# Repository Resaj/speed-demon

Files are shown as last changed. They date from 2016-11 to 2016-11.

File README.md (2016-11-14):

# Speed Demon
Speed Demon es mi primer velocista de competición. Ha participado en Alcabot y Cosmobot.

Es un robot bastante casero porque lo hice en 10 días con una plancha de acero que posteriormente cubrí de laca para que no se oxidara.
Para su primera competición tuve que cambiarle la placa del microcontrolador la tarde de antes porque la inicial daba muchos problemas. Le programé el algoritmo PID en una noche y a la mañana siguiente compitió incluso con aceleración en recta programada un rato antes.

Dio muy buenos resultados y quedó en una posición bastante digna, pero pronto fue sustituido por Pumatrón V2 en su versión velocista.
Los programas "actuales" de Speed Demon que he subido al repositorio quedaron en versión beta precisamente por eso.

<p align="center">
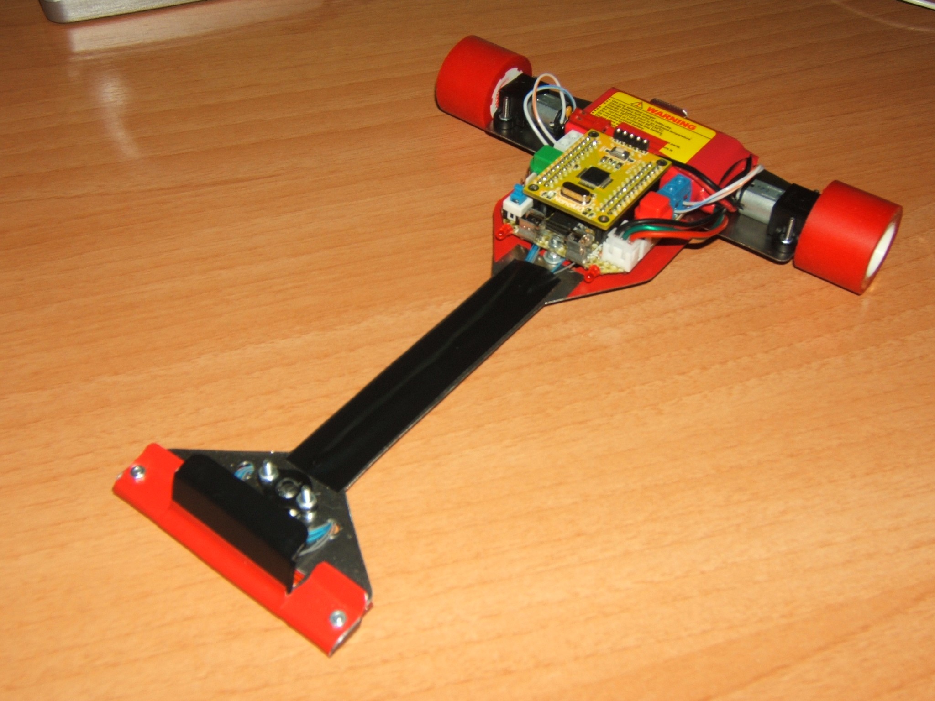
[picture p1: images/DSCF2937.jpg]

</p>

## Autor
[Rubén Espino San José](https://github.com/Resaj)

## License
<p align="center">

</p>

Todos estos productos están liberados mediante [Creative Commons Attribution-ShareAlike 4.0 International License](http://creativecommons.org/licenses/by-sa/4.0/).  
_All these products are released under [Creative Commons Attribution-ShareAlike 4.0 International License](http://creativecommons.org/licenses/by-sa/4.0/)._

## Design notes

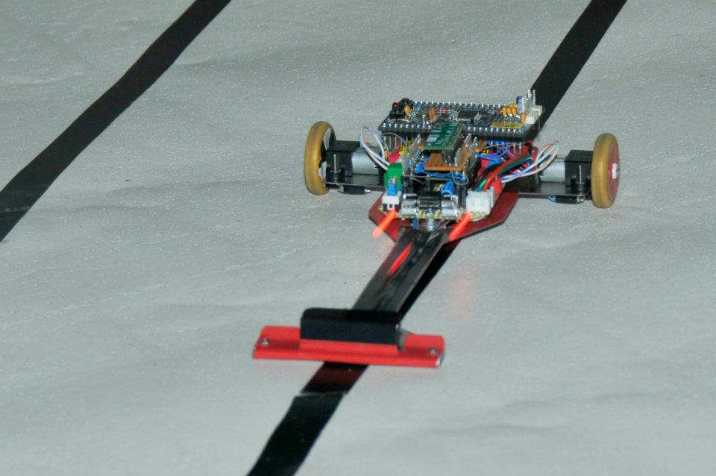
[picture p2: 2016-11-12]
images/542545_299626133457101_100002291494541_641828_2037334963_n.jpg

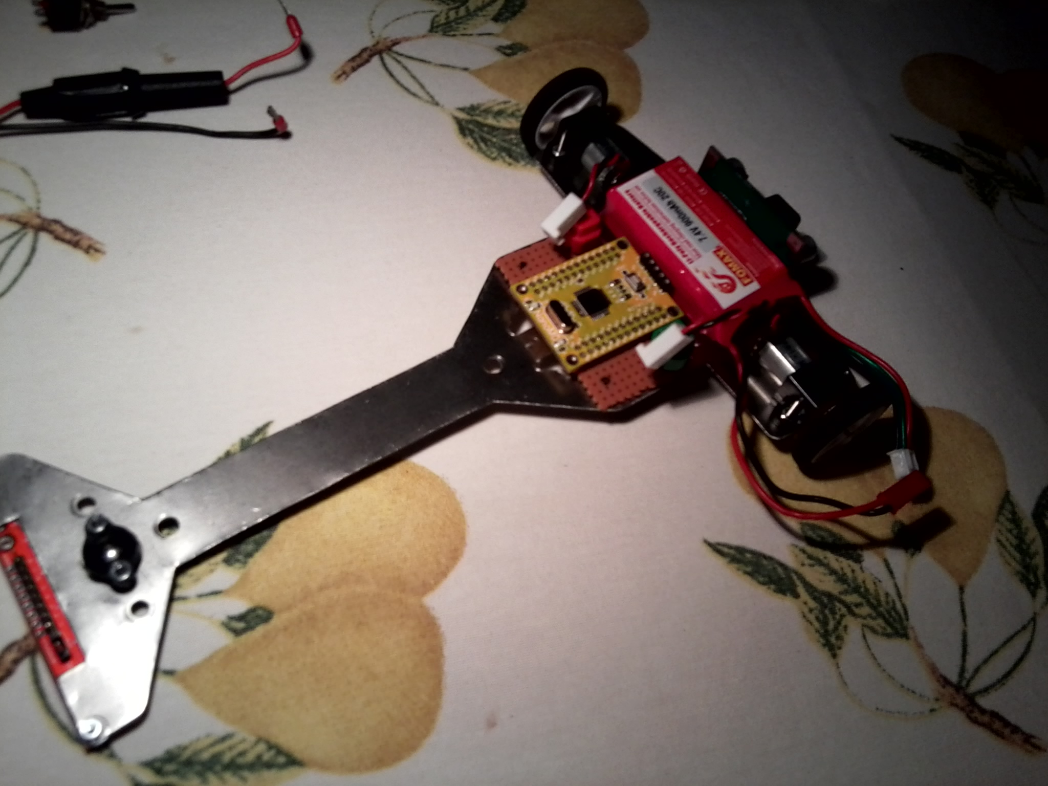
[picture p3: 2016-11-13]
images/Foto0101.jpg

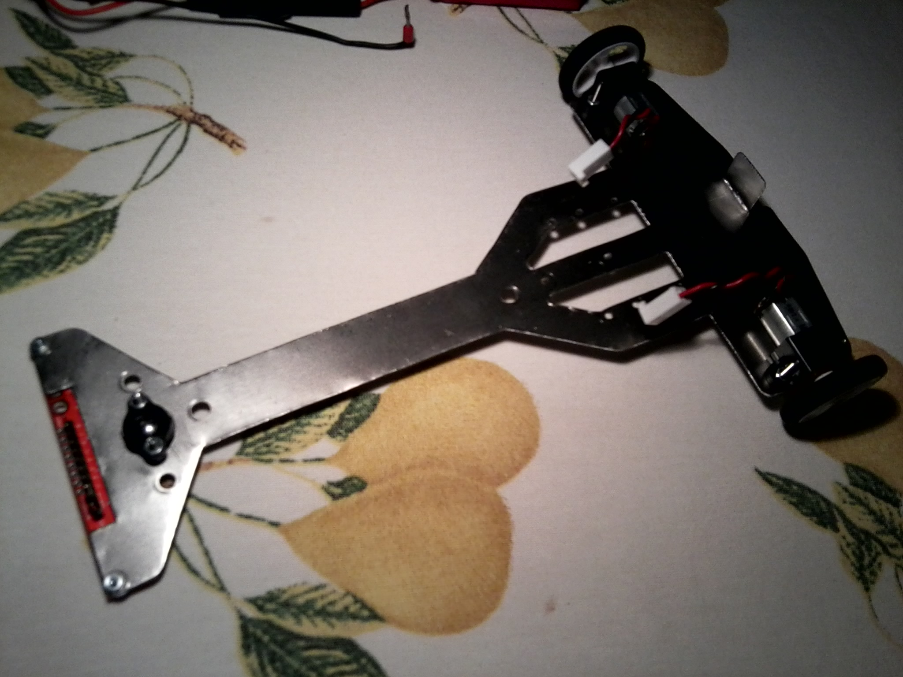
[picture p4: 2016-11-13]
images/Foto0100.jpg

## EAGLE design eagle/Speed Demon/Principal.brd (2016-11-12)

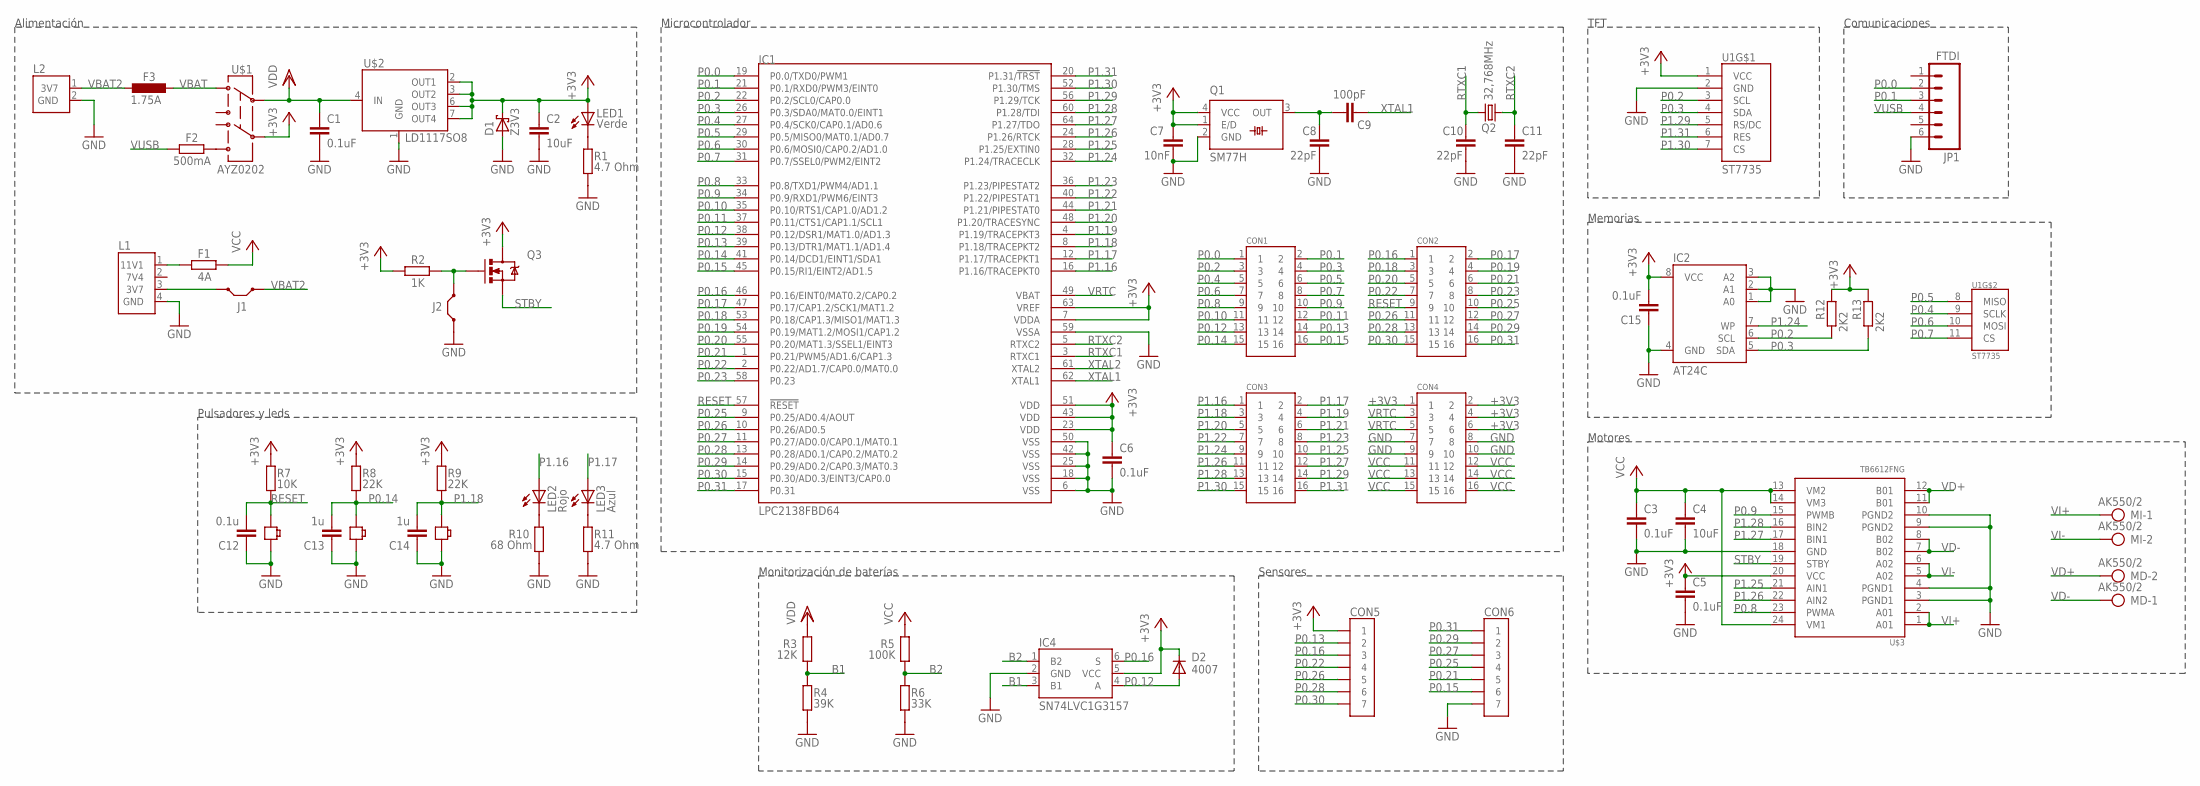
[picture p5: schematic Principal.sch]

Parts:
B1: BUTTON-SMD-2P; BUTTON_2P_SMD
C1, C3, C5, C6, C15: 0.1uF; C0805
C2, C4: 10uF; C1206
C7: 10nF; C0805
C8, C10, C11: 22pF; C0805
C9: 100pF; C0805
C12: 0.1u; C0805
C13, C14: 1u; C0805
CON1, CON2, CON3, CON4: 8X2_PIN_2MM_HEMBRA; 8X2_PIN_2MM
CON5, CON6: 7_PINES; 7_PIN_MACHO_SMD_RA
D1: Z3V3; DO35-7
D2: 4007; SOD106-R
F1: 4A; 2920
F2: 500mA; M1206
F3: 1.75A; L1812
IC1: LPC2138FBD64; TSQFP50P1200X1200X160-64N
IC2: AT24C; 8S1
IC4: SN74LVC1G3157; DBV
J1, J2: JUMPERSMD; 2_PIN_VERT_SMD
JP1: FTDI; 1X06_SMD_STRAIGHT
L1: CONECTOR_LIPO_11.1V
L2: CONECTOR_LIPO_3.7V
LED1: Verde; CHIPLED_0805
LED2: Rojo; CHIPLED_0805
LED3: Azul; CHIPLED_0805
LOAD: BUTTON-SMD-2P; BUTTON_2P_SMD
MD: AK550/2
MI: AK550/2
Q1: SM77H
Q2: 32,768MHz; TC38H
Q3: MOSFET-NCHANNELSMD; SOT23-3
R1, R11: 4.7 Ohm; R0805
R2: 1K; R0805
R3: 12K; R0805
R4: 39K; R0805
R5: 100K; R0805
R6: 33K; R0805
R7: 10K; R0805
R8, R9: 22K; R0805
R10: 68 Ohm; R0805
R12, R13: 2K2; R0805
RESET: BUTTON-SMD-2P; BUTTON_2P_SMD
U1: ST7735
U$1: AYZ0202
U$2: LD1117SO8; SO8
U$3: TB6612FNG; SSOP24

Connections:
7V4: L1.2 (7V4)
+3V3: C2.1, C5.1, C6.1, C7.1, C15.2, CON4.1, CON4.2, CON4.4, CON4.6, CON5.P$1 (1), D1.C, D2.C, IC1.7 (VDDA), IC1.23 (VDD), IC1.43 (VDD), IC1.51 (VDD), IC1.63 (VREF), IC2.8 (VCC), IC4.5 (VCC), LED1.A, Q1.1 (E/D), Q1.4 (VCC), Q3.3 (D), R2.2, R7.2, R8.2, R9.2, R12.2, R13.2, U1.1 (VCC), U$1.5, U$2.2 (OUT1), U$2.3 (OUT2), U$2.6 (OUT3), U$2.7 (OUT4), U$3.20 (VCC)
B1: IC4.3 (B1), R3.1, R4.2
B2: IC4.1 (B2), R5.1, R6.2
GND: B1.P$2, C1.2, C2.2, C3.2, C4.2, C5.2, C6.2, C7.2, C8.2, C10.2, C11.2, C12.1, C13.1, C14.1, C15.1, CON4.7, CON4.8, CON4.9, CON4.10, CON6.P$7 (7), D1.A, IC1.6 (VSS), IC1.18 (VSS), IC1.25 (VSS), IC1.42 (VSS), IC1.50 (VSS), IC1.59 (VSSA), IC2.1 (A0), IC2.2 (A1), IC2.3 (A2), IC2.4 (GND), IC4.2 (GND), J2.1, JP1.6, L1.4 (GND), L2.2 (GND), LOAD.P$2, Q1.2 (GND), R1.2, R4.1, R6.1, R10.2, R11.2, RESET.P$2, U1.2 (GND), U$2.1 (GND), U$3.3 (PGND1), U$3.4 (PGND1), U$3.9 (PGND2), U$3.10 (PGND2), U$3.18 (GND)
unnamed: LED2.C, R10.1
unnamed: LED3.C, R11.1
unnamed: J2.2, Q3.1 (G), R2.1
unnamed: F2.1, U$1.4 (6)
unnamed: F1.1, L1.1 (11V1)
unnamed: J1.2, L1.3 (3V7)
unnamed: LED1.C, R1.1
unnamed: C8.1, C9.1, Q1.3 (OUT)
P0.0: CON1.1, IC1.19 (P0.0/TXD0/PWM1), JP1.2
P0.1: CON1.2, IC1.21 (P0.1/RXD0/PWM3/EINT0), JP1.3
P0.2: CON1.3, IC1.22 (P0.2/SCL0/CAP0.0), IC2.6 (SCL), R12.1, U1.3 (SCL)
P0.3: CON1.4, IC1.26 (P0.3/SDA0/MAT0.0/EINT1), IC2.5 (SDA), R13.1, U1.4 (SDA)
P0.4: CON1.5, IC1.27 (P0.4/SCK0/CAP0.1/AD0.6), U1.9 (SCLK)
P0.5: CON1.6, IC1.29 (P0.5/MISO0/MAT0.1/AD0.7), U1.8 (MISO)
P0.6: CON1.7, IC1.30 (P0.6/MOSI0/CAP0.2/AD1.0), U1.10 (MOSI)
P0.7: CON1.8, IC1.31 (P0.7/SSEL0/PWM2/EINT2), U1.11 (CS)
P0.8: CON1.9, IC1.33 (P0.8/TXD1/PWM4/AD1.1), U$3.23 (PWMA)
P0.9: CON1.10, IC1.34 (P0.9/RXD1/PWM6/EINT3), U$3.15 (PWMB)
P0.10: CON1.11, IC1.35 (P0.10/RTS1/CAP1.0/AD1.2)
P0.11: CON1.12, IC1.37 (P0.11/CTS1/CAP1.1/SCL1)
P0.12: CON1.13, D2.A, IC1.38 (P0.12/DSR1/MAT1.0/AD1.3), IC4.4 (A)
P0.13: CON1.14, CON5.P$2 (2), IC1.39 (P0.13/DTR1/MAT1.1/AD1.4)
P0.14: C13.2, CON1.15, IC1.41 (P0.14/DCD1/EINT1/SDA1), LOAD.1, R8.1
P0.15: CON1.16, CON6.P$6 (6), IC1.45 (P0.15/RI1/EINT2/AD1.5)
P0.16: CON2.1, CON5.P$3 (3), IC1.46 (P0.16/EINT0/MAT0.2/CAP0.2), IC4.6 (S)
P0.17: CON2.2, IC1.47 (P0.17/CAP1.2/SCK1/MAT1.2)
P0.18: CON2.3, IC1.53 (P0.18/CAP1.3/MISO1/MAT1.3)
P0.19: CON2.4, IC1.54 (P0.19/MAT1.2/MOSI1/CAP1.2)
P0.20: CON2.5, IC1.55 (P0.20/MAT1.3/SSEL1/EINT3)
P0.21: CON2.6, CON6.P$5 (5), IC1.1 (P0.21/PWM5/AD1.6/CAP1.3)
P0.22: CON2.7, CON5.P$4 (4), IC1.2 (P0.22/AD1.7/CAP0.0/MAT0.0)
P0.23: CON2.8, IC1.58 (P0.23)
P0.25: CON2.10, CON6.P$4 (4), IC1.9 (P0.25/AD0.4/AOUT)
P0.26: CON2.11, CON5.P$5 (5), IC1.10 (P0.26/AD0.5)
P0.27: CON2.12, CON6.P$3 (3), IC1.11 (P0.27/AD0.0/CAP0.1/MAT0.1)
P0.28: CON2.13, CON5.P$6 (6), IC1.13 (P0.28/AD0.1/CAP0.2/MAT0.2)
P0.29: CON2.14, CON6.P$2 (2), IC1.14 (P0.29/AD0.2/CAP0.3/MAT0.3)
P0.30: CON2.15, CON5.P$7 (7), IC1.15 (P0.30/AD0.3/EINT3/CAP0.0)
P0.31: CON2.16, CON6.P$1 (1), IC1.17 (P0.31)
P1.16: CON3.1, IC1.16 (P1.16/TRACEPKT0), LED2.A
P1.17: CON3.2, IC1.12 (P1.17/TRACEPKT1), LED3.A
P1.18: B1.1, C14.2, CON3.3, IC1.8 (P1.18/TRACEPKT2), R9.1
P1.19: CON3.4, IC1.4 (P1.19/TRACEPKT3)
P1.20: CON3.5, IC1.48 (P1.20/TRACESYNC)
P1.21: CON3.6, IC1.44 (P1.21/PIPESTAT0)
P1.22: CON3.7, IC1.40 (P1.22/PIPESTAT1)
P1.23: CON3.8, IC1.36 (P1.23/PIPESTAT2)
P1.24: CON3.9, IC1.32 (P1.24/TRACECLK), IC2.7 (WP)
P1.25: CON3.10, IC1.28 (P1.25/EXTIN0), U$3.21 (AIN1)
P1.26: CON3.11, IC1.24 (P1.26/RTCK), U$3.22 (AIN2)
P1.27: CON3.12, IC1.64 (P1.27/TDO), U$3.17 (BIN1)
P1.28: CON3.13, IC1.60 (P1.28/TDI), U$3.16 (BIN2)
P1.29: CON3.14, IC1.56 (P1.29/TCK), U1.5 (RS/DC)
P1.30: CON3.15, IC1.52 (P1.30/TMS), U1.7 (CS)
P1.31: CON3.16, IC1.20 (P1.31/!TRST), U1.6 (RES)
RESET: C12.2, CON2.9, IC1.57 (!RESET), R7.1, RESET.1
RTXC1: C10.1, IC1.3 (RTXC1), Q2.2
RTXC2: C11.1, IC1.5 (RTXC2), Q2.1
STBY: Q3.2 (S), U$3.19 (STBY)
VBAT: F3.1, U$1.3 (1)
VBAT2: F3.2, J1.1, L2.1 (3V7)
VCC: C3.1, C4.1, CON4.11, CON4.12, CON4.13, CON4.14, CON4.15, CON4.16, F1.2, R5.2, U$3.13 (VM2), U$3.14 (VM3), U$3.24 (VM1)
VD+: MD.2, U$3.11 (B01), U$3.12 (B01)
VD-: MD.1, U$3.7 (B02), U$3.8 (B02)
VDD: C1.1, R3.2, U$1.2, U$2.4 (IN)
VI+: MI.1, U$3.1 (A01), U$3.2 (A01)
VI-: MI.2, U$3.5 (A02), U$3.6 (A02)
VRTC: CON4.3, CON4.5, IC1.49 (VBAT)
VUSB: F2.2, JP1.4
XTAL1: C9.2, IC1.62 (XTAL1)
XTAL2: IC1.61 (XTAL2)

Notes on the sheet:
Memorias
Alimentación
Sensores
Comunicaciones
Motores
Pulsadores y leds
Microcontrolador
Monitorización de baterías
TFT

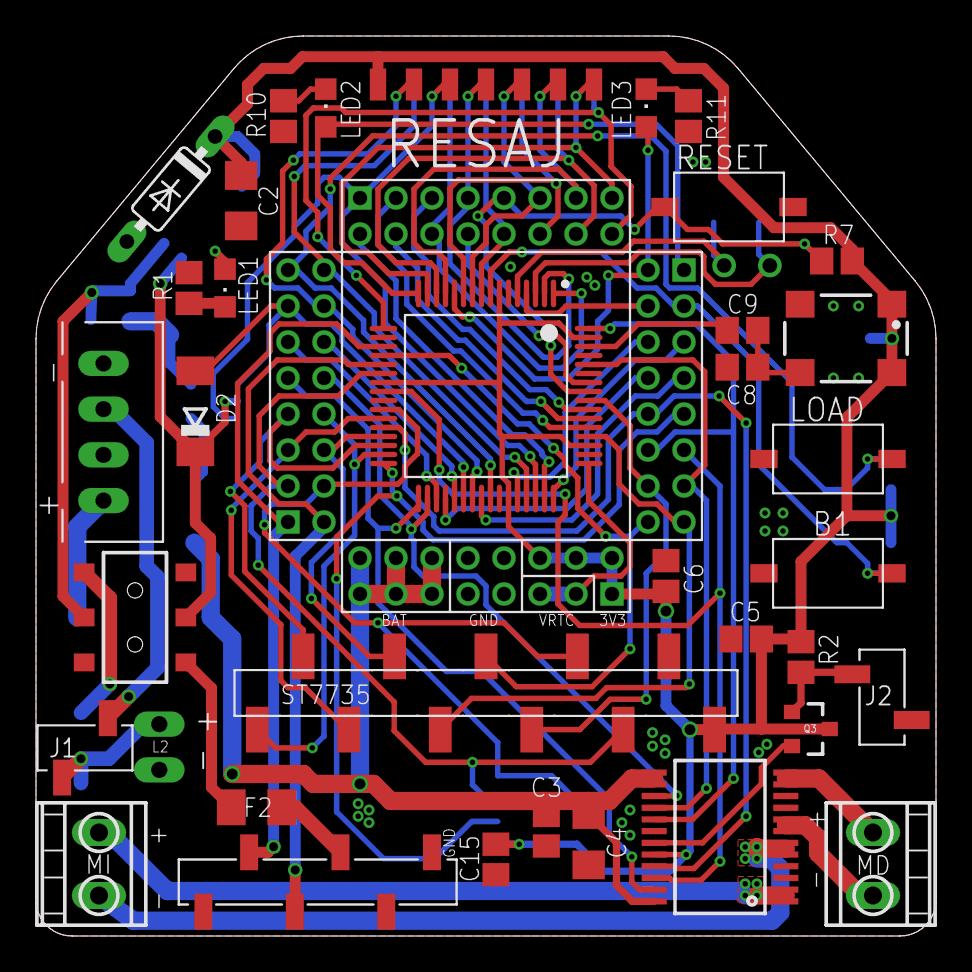
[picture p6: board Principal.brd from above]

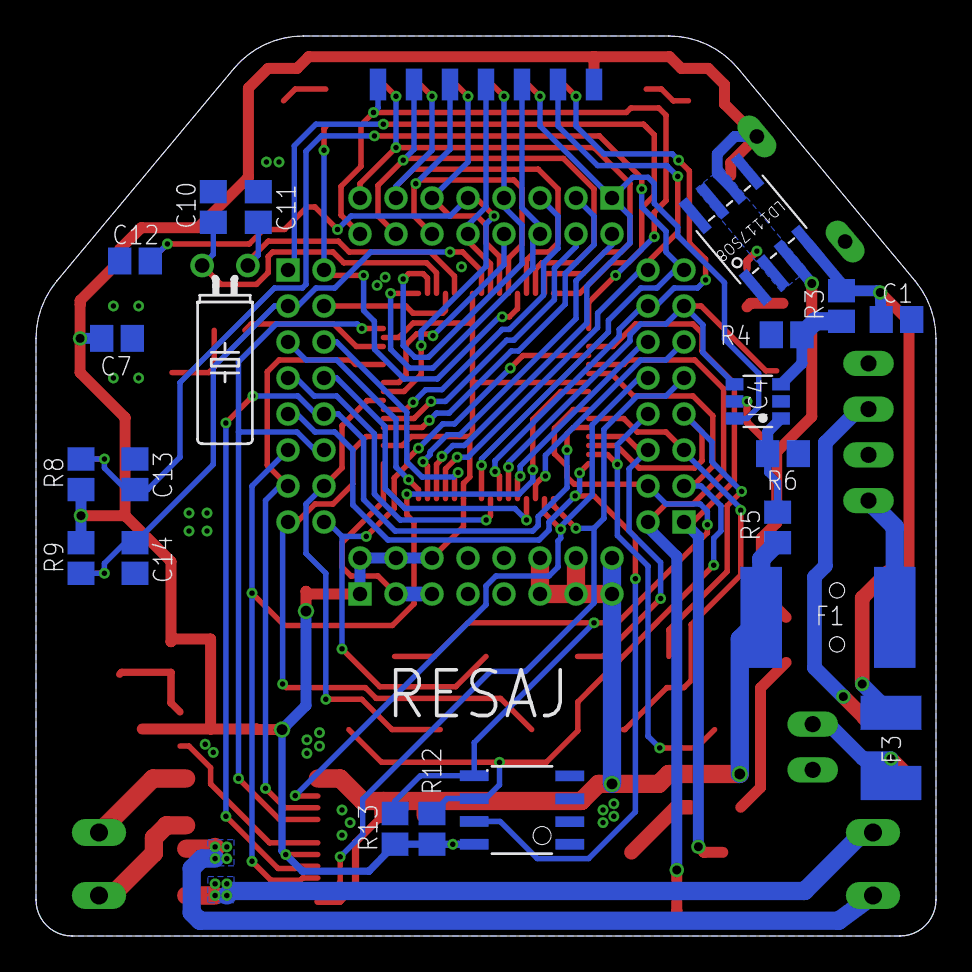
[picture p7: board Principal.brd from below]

Board: 2 copper layers, 50.0 x 50.0 mm, 62 parts (22 on the bottom side), 74 nets.

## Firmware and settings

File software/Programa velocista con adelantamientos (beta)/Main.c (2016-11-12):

#include <lpc213x.h>
#include <stdbool.h>
#include <stdio.h>
#include "LPClib.h"
#include "declaraciones.h"
#include "target.h"
#include "s1d15g00.h"
#include "motors.h"


/************************ VARIABLES ************************/
// Variables auxiliares 
char ESTADO = Seleccion_velocidad, ESTADO_RASTREO = Rastreo_normal;
char cadena[200];			// Variable auxiliar para guardar el texto a imprimir en el LCD
float cont_load = 0, cont_b1 = 0, cont_stop = 0,  cont_start = 0, cont_ready = 0, cont_espera = 0, cont_bat = BAT_PERIOD, cont_blinky = 0;
char flag = ON, button_load = OFF, button_b1 = OFF, button_stop = OFF;
float cont_sel = 0;
float cont_cambio_lin = 0;
int cont_dist = 0;
unsigned long captura_izq = 0, captura_der = 0;
unsigned long enc_izq = 0, enc_der = 0;
unsigned int cont_enc_izq = 0, cont_enc_der = 0;
char blinky = OFF;
char uart0_dato = '0';

unsigned int seg_espera = 0;
char color_suelo = BLANCO;

// Variables para el control del rastreo
unsigned int ADCresult[S];		// Array con los datos del ADC ordenados
unsigned int ADCdist;

unsigned int umbral[S];			// Umbral para diferenciar blanco y negro en la lectura del sensor
unsigned int blanco[S];	
unsigned int negro[S];

char giro = '0', giro_ant;		// Variable auxiliar para no perder la línea. Se inicia a un valor distinto a IZQ y DER
int negros = 0;					// Número de sensores en negro
char lin = '3';					// Línea a seguir

// Variables para el control de velocidad
float v_rapida = 60;			// Control de velocidad de rastreo normal. 1 max
//float velocidad = 60;			// Velocidad de rastreo. Entre 0 y 100
float w = 0, v = 0;
//float v_izq_real = 0, v_der_real = 0, vl_real = 0, w_real = 0;
char mode_izq = FORWARD, mode_der = FORWARD;

//Variables del PID de velocidad angular
float proportional = 0;
float integral = 0;
float integral_max = 1;
float w_ctrl_max = 3;
float Kp = 1;
float Ki = 0;
float Kd = 70;


// Sensores
struct analog LINE_1	= {ADC_1,ADC_CH6};	// Número y canal de ADC para el sensor de línea 1
struct analog LINE_2	= {ADC_1,ADC_CH7};	// Número y canal de ADC para el sensor de línea 2
struct analog LINE_3	= {ADC_0,ADC_CH4};	// Número y canal de ADC para el sensor de línea 3
struct analog LINE_4	= {ADC_0,ADC_CH5};	// Número y canal de ADC para el sensor de línea 4
struct analog LINE_5	= {ADC_0,ADC_CH0};	// Número y canal de ADC para el sensor de línea 5
struct analog LINE_6	= {ADC_0,ADC_CH1};	// Número y canal de ADC para el sensor de línea 6
struct analog LINE_7	= {ADC_0,ADC_CH2};	// Número y canal de ADC para el sensor de línea 7
struct analog LINE_8	= {ADC_0,ADC_CH3};	// Número y canal de ADC para el sensor de línea 8

struct analog DIST		= {ADC_0,ADC_CH6};	// Sensor de distancia frontal

// Batería
struct analog BAT_ADC	= {ADC_1,ADC_CH3};	// Número y canal de ADC para la batería
struct data MUX			= {0,16};			// Puerto y pin del multiplexor

// Pulsadores
struct data BUTTON_LOAD	= {0,14};	// Puerto y pin del pulsador de load
struct data BUTTON_B1	= {1,18};	// Puerto y pin del pulsador B1
struct data BUTTON_STOP	= {1,21};	// Puerto y pin del pulsador de start/stop

// Leds
struct data LED_1	= {1,16};		// Puerto y pin del led 1
struct data LED_2	= {1,17};		// Puerto y pin del led 2

// Motores
struct data MI_pos	= {1,26};		// Control de Puente en H +, rama izquierda
struct data MI_neg	= {1,25};		// Control de Puente en H -, rama izquierda
struct data MD_pos	= {1,27};		// Control de Puente en H +, rama derecha
struct data MD_neg	= {1,28};		// Control de Puente en H -, rama derecha

struct motor MOTOR_IZQ	= {MI_PWM,{1,26},{1,25}};
struct motor MOTOR_DER	= {MD_PWM,{1,27},{1,28}};

// Encoders
struct data ENC_IZQ	= {0,10};		// Puerto y pin del encoder izquierdo
struct data ENC_DER	= {0,11};		// Puerto y pin del encoder derecho


/************************ FUNCIONES DE CONFIGURACIÓN ************************/
void config_SPEED_DEMON(void)
{
	config_ADC();
	config_BUTTONS();
//	config_LCD();
	config_LEDS();
	config_MOTORS();
	config_UART();
//	config_CAPTURE();
	config_PERIODIC_CONTROL();
}

void config_LINE_SENSORS(void)
{
	ADC_CH_config(LINE_1);
	ADC_CH_config(LINE_2);
	ADC_CH_config(LINE_3);
	ADC_CH_config(LINE_4);
	ADC_CH_config(LINE_5);
	ADC_CH_config(LINE_6);
	ADC_CH_config(LINE_7);
	ADC_CH_config(LINE_8);
}

void config_DIST_SENSORS(void)
{
	ADC_CH_config(DIST);
}

void config_BATTERY_ADC(void)
{
	ADC_CH_config(BAT_ADC);
	GPIO_config(MUX, OUT);
}

void config_ADC(void)
{
	config_LINE_SENSORS();
	config_DIST_SENSORS();
	config_BATTERY_ADC();

	ADC_enable(ADC_0);
	ADC_enable(ADC_1);
}

void config_BUTTONS(void)
{
	GPIO_config(BUTTON_LOAD, IN);
	GPIO_config(BUTTON_B1, IN);
	GPIO_config(BUTTON_STOP, IN);
}

void config_LCD(void)
{
	LCD_BL_DIR();			// BL = Output
	LCD_CS_DIR();			// CS = Output
	LCD_SCLK_DIR();			// SCLK = Output
	LCD_SDATA_DIR();		// SDATA = Output
	LCD_RESET_DIR();		// RESET = Output
	LCD_SCLK_LOW();			// Standby SCLK
	LCD_CS_HIGH();			// Disable CS
	LCD_SDATA_HIGH();		// Standby SDATA
	LCD_BL_HIGH();			// Black Light ON = 100%
	
	InitLcd(); 				// Initial LCD
	LCDClearScreen();		// Limpiar pantalla
}

void config_LEDS(void)
{
	GPIO_config(LED_1, OUT);
	GPIO_config(LED_2, OUT);
}

void config_MOTORS(void)
{
	MOTOR_config(MOTOR_IZQ);
	MOTOR_config(MOTOR_DER);
											 
	PWM_enable(PWM_PERIOD);
}

void config_UART(void)
{
	UART0_config(115200, UART_PRIO);
}

void config_CAPTURE(void)
{
	CAPTURE_CHANNEL_config(ENC_IZQ_CH, ENC_IZQ, DOUBLE_EDGE);
	CAPTURE_CHANNEL_config(ENC_DER_CH, ENC_DER, DOUBLE_EDGE);

	TIMER_config(CAPTURE_TIMER, CAPTURE_MODE, CAPTURE_PRIO);
}

void config_PERIODIC_CONTROL(void)
{
	MATCH_CHANNEL_config(PERIODIC_CH, PER_PERIOD);
	TIMER_config(MATCH_TIMER, MATCH_MODE, MATCH_PRIO);
}


/************************** FUNCIÓN MAIN **************************/
int main (void)
{
	inicializar_umbrales(50, 400, 800);

	config_SPEED_DEMON();

	LED_set(LED_1, ON);
	LED_set(LED_2, ON);

	while(1) // Bucle infinito para la ejecución del programa
	{
		if(uart0_dato == 'l')
		{
			sprintf(cadena, "%4u %4u %4u %4u %4u %4u %4u %4u\n\r", ADCresult[0], ADCresult[1], ADCresult[2], ADCresult[3],
				ADCresult[4], ADCresult[5], ADCresult[6], ADCresult[7]);
			UART0_send(cadena);
		}
		else if(uart0_dato == 'u')
		{
			sprintf(cadena, "%4u %4u %4u %4u %4u %4u\n\r%4u %4u %4u %4u %4u %4u\n\r%4u %4u %4u %4u %4u %4u\n\r", blanco[0],
				blanco[1], blanco[2], blanco[3], blanco[4], blanco[5], umbral[0], umbral[1], umbral[2], umbral[3], umbral[4],
				umbral[5], negro[0], negro[1], negro[2], negro[3], negro[4], negro[5]);
			UART0_send(cadena);
		}
		else if(uart0_dato == 'd')
		{
			sprintf(cadena, "%d\n\r", ADCdist);
			UART0_send(cadena);
		}
		else if(uart0_dato == 'm')
		{
			sprintf(cadena, "%4f\t%4f\n\r", w, v);
			UART0_send(cadena);
		}
	}
}

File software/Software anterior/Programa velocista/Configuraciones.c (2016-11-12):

#include <lpc213x.h>
#include "Declaraciones.h"

/************************ CONFIGURACIONES ************************/
// Configuración del ADC0 para los sensores de línea
void config_ADC0 (void)
{
	PINSEL0 |= (1<<8)|(1<<9)|(1<<10)|(1<<11);		// Habilitar ADC0[6,7]
	PINSEL1 |= (1<<18)|(1<<20)|(1<<22)|(1<<24)|(1<<26)|(1<<28);	// Habilitar ADC0[0..5]

	VICVectAddr2 = (unsigned long) ADC0;
	VICVectCntl2 = (0x20|18);
	VICIntEnable |= (1<<18);

	AD0CR = 0x2103FF;	// Activación de la conversión en modo burst para los 8 canales de ADC0
}

// Configuración del Match0.2 del TIMER0
void config_TIMER0 (void)
{
	T0TCR = 0x02;
	T0PR = 0;
	T0MCR = (1<<6)|(1<<7);
	T0MR2 = (unsigned long)(Periodo*Fpclk);
	VICVectAddr1 = (unsigned long) TIMER0;
	VICVectCntl1 = (0x20|4);
	T0TCR = 0x01;
	VICIntEnable |= 1<<4;
}

// Configuración del Capture1.2 y Capture1.3
void config_TIMER1(void)
{
	PINSEL1 |= (1<<2)|(1<<4);
	T1TCR = 0x02;
	T1CTCR = 0;
	T1PR = 0;
	T1TCR = 0x01;
 	T1CCR = (7<<6)|(7<<9);
	VICVectCntl0 = (0x20|5);
	VICVectAddr0 = (unsigned long) TIMER1;
	VICIntEnable |= (1<<5);
}

// Configuración de las salidas de PWM para los motores
void config_MOTORES (void)
{
	IO1PIN &= ~(1<<16);
	PINSEL0 |= (1<<15)|(1<<19);					// PWM2 y PWM6
	IO1DIR |= (1<<21)|(1<<22)|(1<<27)|(1<<28);	// Salidas para el sentido de los motores
	PWMTCR = 0x02;								// Reset TIMER y PREESCALER										   
	PWMPR = 0;									// El PRESCALER no modifica la frecuencia
	PWMMR0 = Per_pwm * Fpclk;					// Periodo PWM									   
	PWMLER = (1<<0)|(1<<2)|(1<<6);				// Habilitar MATCH0, MATCH2 y MATCH6
	PWMMCR = 0x02;								// Reset TIMER COUNTER REGISTER ON MATCH0							   
	PWMPCR = (1<<10)|(1<<14);					// Habilitar PWM2 y PWM6 en flanco
	PWMTCR = (1<<0)|(1<<3);						// Habilitar PWM y comenzar la cuenta
}

// Configuración de los leds
void config_leds(void)
{
	IO1DIR |= (1<<25)|(1<<30);
}

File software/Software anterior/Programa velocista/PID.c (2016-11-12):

#include <lpc213x.h>
#include "Declaraciones.h"
#include "PID.h"

/********************** ALGORITMO PID **********************/
void get_PID(void)
{
	sensors_average = 0;
	for(i = 0; i < S; i++)
		sensors_average += LINEAresult[i]*i*1000;

	sensors_sum = 0;
	for(i = 0; i < S; i++)
		sensors_sum += LINEAresult[i];

	if(sensors_sum == 0)
	{
		if(last_proportional > 0)
			position = S*1000;
		else // last_proportional < 0
			position = 0;
	}
	else // sensors_sum != 0
		position = (sensors_average / sensors_sum);

	proportional = position - (S-1)*1000/2;
	integral = integral + proportional;
	derivative = proportional - last_proportional;
	last_proportional = proportional;

	control_value = (float)(proportional * Kp + integral * Ki + derivative * Kd);
}

void set_motors(void)
{
	if(sensors_sum == 0)
	{
		if(control_value > 0)
		{
			cont = 0;
			velocidad = v_lenta;

			IO1PIN &= ~((1<<22)|(1<<25));
			IO1PIN |= (1<<28)|(1<<30);
			PWMMR2 = (float)velocidad*Per_pwm*Fpclk;
		}
		else if(control_value < 0)
		{
			cont = 0;
			velocidad = v_lenta;

			IO1PIN &= ~((1<<28)|(1<<30));
			IO1PIN |= (1<<22)|(1<<25);
			PWMMR6 = (float)velocidad*Per_pwm*Fpclk;
		}
	}
	else
	{
		if(control_value > max_difference)
			control_value = max_difference;
		else if(control_value < -max_difference)
			control_value = -max_difference;


		if(control_value > max_difference/2)
		{
			if(frenar == 1)
			{
				IO1PIN |= (1<<22);
				IO1PIN |= (1<<28);
				PWMMR6 = (float)velocidad*Per_pwm*Fpclk;
				PWMMR2 = (float)(control_value - max_difference/2)/(max_difference/2) * velocidad*Per_pwm*Fpclk;
			}
			else
			{
				IO1PIN &= ~(1<<22);
				IO1PIN |= (1<<28);
				PWMMR2 = (float)velocidad*Per_pwm*Fpclk;
				PWMMR6 = (float)(control_value - max_difference/2)/(max_difference/2) * velocidad*Per_pwm*Fpclk;
			}
		}
		else if(control_value < -max_difference/2)
		{
			if(frenar == 1)
			{
				IO1PIN |= (1<<22);
				IO1PIN |= (1<<28);

				PWMMR6 = (float)(-control_value - max_difference/2)/(max_difference/2) * velocidad*Per_pwm*Fpclk;
				PWMMR2 = (float)velocidad*Per_pwm*Fpclk;
			}
			else
			{
				IO1PIN &= ~(1<<28);
				IO1PIN |= (1<<22);

				PWMMR2 = (float)(-control_value - max_difference/2)/(max_difference/2) * velocidad*Per_pwm*Fpclk;
				PWMMR6 = (float)velocidad*Per_pwm*Fpclk;
			}
		}
		else
		{
			IO1PIN &= ~((1<<28)|(1<<22));
			IO1PIN |= (1<<25)|(1<<30);
	
			if(control_value < 0)
			{
				if(frenar == 1)
				{
					IO1PIN |= (1<<22);
					IO1PIN |= (1<<28);

					PWMMR2 = (float)velocidad*Per_pwm*Fpclk;
					PWMMR6 = (float)(max_difference + control_value)/max_difference * velocidad*Per_pwm*Fpclk;
				}
				else
				{
					PWMMR2 = (float)(max_difference + control_value)/max_difference * velocidad*Per_pwm*Fpclk;
					PWMMR6 = (float)velocidad*Per_pwm*Fpclk;
				}
			}
			else if(control_value > 0)
			{
				if(frenar == 1)
				{
					IO1PIN |= (1<<22);
					IO1PIN |= (1<<28);

					PWMMR2 = (float)(max_difference - control_value)/max_difference * velocidad*Per_pwm*Fpclk;
					PWMMR6 = (float)velocidad*Per_pwm*Fpclk;

				}
				else
				{	
					PWMMR2 = (float)velocidad*Per_pwm*Fpclk;
					PWMMR6 = (float)(max_difference - control_value)/max_difference * velocidad*Per_pwm*Fpclk;
				}
			}
			else
			{
				if(frenar == 1)
				{
					IO1PIN |= (1<<22);
					IO1PIN |= (1<<28);

					PWMMR2 = velocidad*Per_pwm*Fpclk;
					PWMMR6 = velocidad*Per_pwm*Fpclk;					
				}
				else
				{	
					PWMMR2 = velocidad*Per_pwm*Fpclk;
					PWMMR6 = velocidad*Per_pwm*Fpclk;
				}
			}
		}
	}

	PWMLER = (1<<0)|(1<<2)|(1<<6);
}

void loop_PID(void)
{
	get_PID();
	set_motors();
}

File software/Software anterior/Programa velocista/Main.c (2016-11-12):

#include <lpc213x.h>
#include <stdbool.h>
#include "Declaraciones.h"
#include "PID.h"

/************************ VARIABLES ************************/
char ESTADO = Parado;

float Periodo = 5e-3;			// Periodo de ejecución del timer en modo match
float Per_pwm = 1e-3;			// Periodo de la PWM0

// Variables auxiliares 
float cont = 0;
int i = 0;
int t = 0;
int v = 0;
int flag = 1;
float start = 0;
float stop = 0;
int encoder_izq = 0;
int encoder_der = 0;
float radio[20];
int cond = 0;

// Variables para el control del rastreo
unsigned int ADCresult[S];		// Array con los datos del ADC ordenados
unsigned int LINEAresult[S];	// Array que contiene los valores digitalizados de ADCresult
unsigned long r, ch;			// Variables para guardar los datos del ADC

unsigned int umbral[S];			// Umbral para diferenciar 0 y 1 en la lectura del sensor
unsigned int blanco[S];	
unsigned int negro[S];

// Variables para el control de velocidad
float v_lenta = 0.5;			// Velocidad mínima en curva. 1 max
float v_rapida = 0.65;				// Velocidad máxima en recta. 1 max
int frenar = 0;
float velocidad = 0.5;			// Velocidad de rastreo

//Variables PID
int sensors_average = 0;
int sensors_sum = 0;
float position = 0;
float proportional = 0;
float integral = 0;
float derivative = 0;
float last_proportional = 0;
float control_value = 0;
int max_difference = (S-1)*1000/2;
float Kp = 3;	//1.5
float Ki = 0;
float Kd = 25;	//20


/************************** FUNCIÓN MAIN **************************/
int main (void)
{
	// Actualizar umbrales
	for(i=0; i<S; i++)
		umbral[i] = 600;

	// Iniciar vector de radios
	for(i=0; i<20; i++)
		radio[i] = -1;

	// Encender leds
	IO1PIN |= 1<<25;
	IO1PIN |= 1<<30;

	// Motores siempre hacia delante o frenados
	IO1PIN |= (1<<21)|(1<<27);
	IO1PIN &= ~((1<<22)|(1<<28));

	// Configuraciones previas
	config_leds();
	config_MOTORES();
	config_TIMER1();
	config_ADC0();
	config_TIMER0();

	while(1);
}
